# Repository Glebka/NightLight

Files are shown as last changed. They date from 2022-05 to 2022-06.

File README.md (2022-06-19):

# NightLight

This is device that will shade some light on your road to the kitchen at night :)

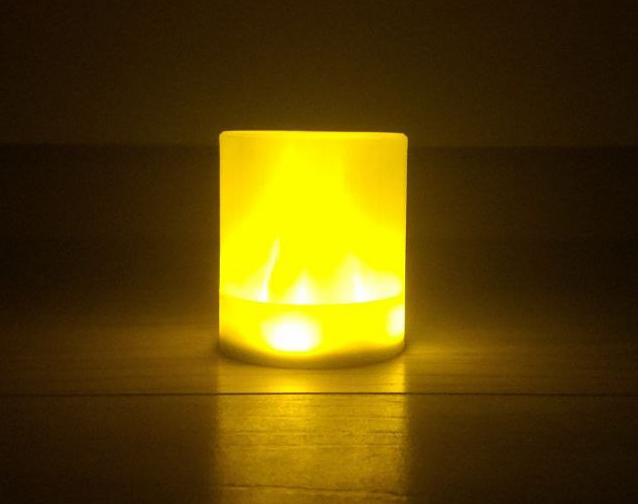
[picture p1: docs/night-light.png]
NightLight device


Well, this is simple electric LED light that powers from small Li-Pol cell (around 60 mAh capacity).

It supports three modes:
- **Off** - no light, charging enabled
- **Always on** - light always on
- **On for a period of time after motion detected** - yep, I've integrated a cheap microwave motion detector. When it triggers - the light turns on for approximately 3 minutes (that is enough time to grab something tasty in the kitchen and get back) and then turns off automatically.

## 3D View

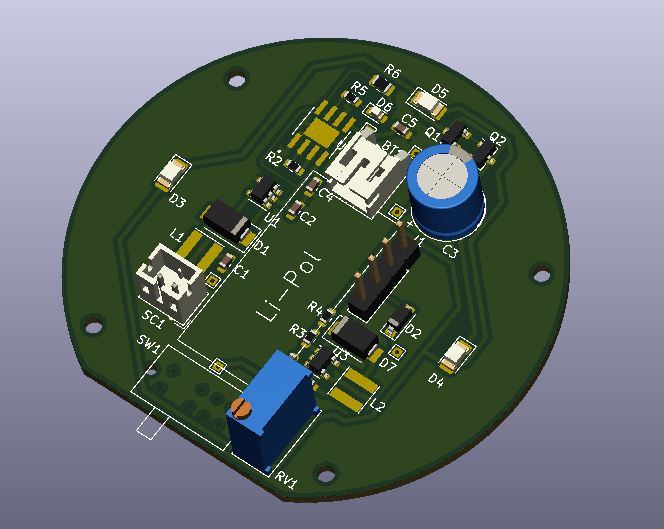
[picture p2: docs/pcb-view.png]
PCB in 3D


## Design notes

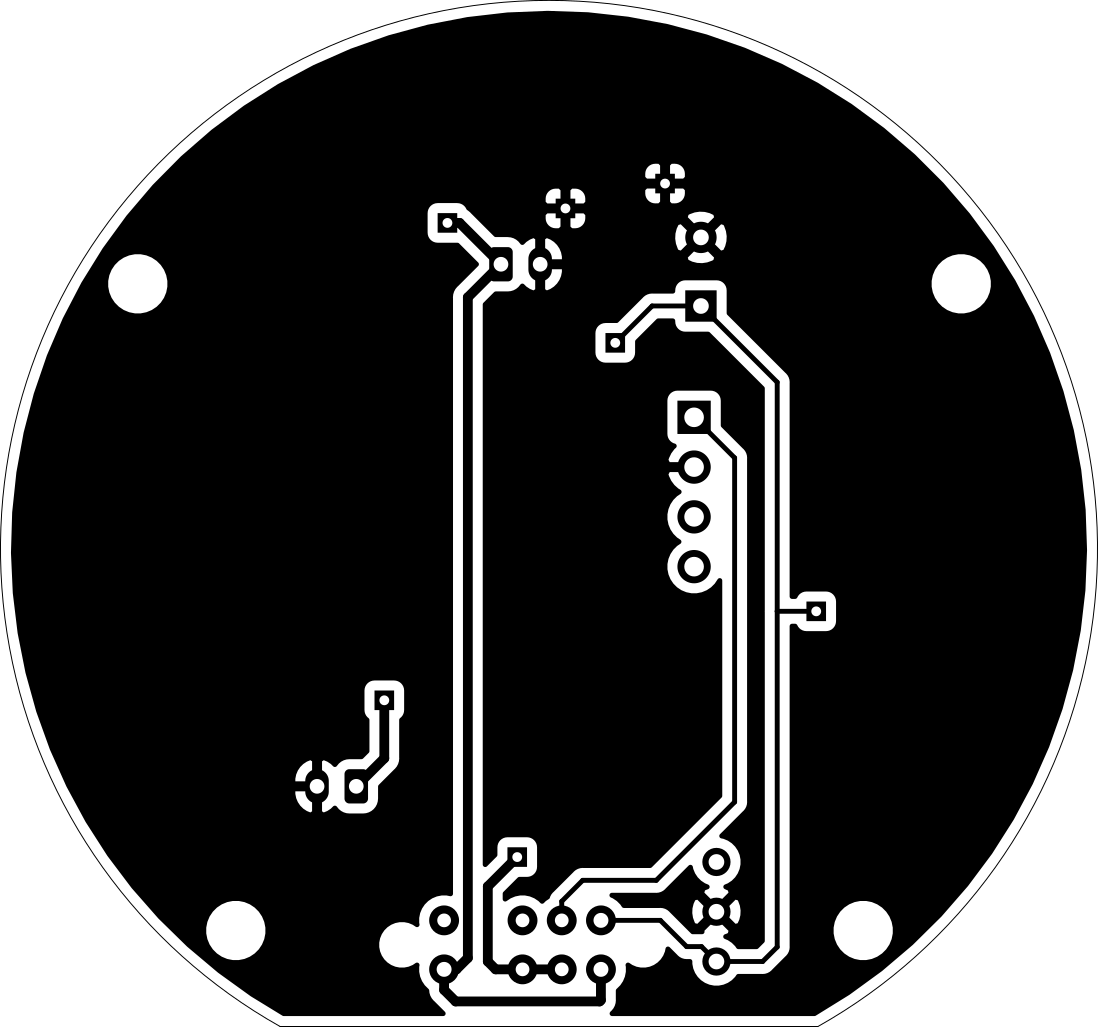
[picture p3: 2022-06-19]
cad/electronics/v2/svg/b-cu.png

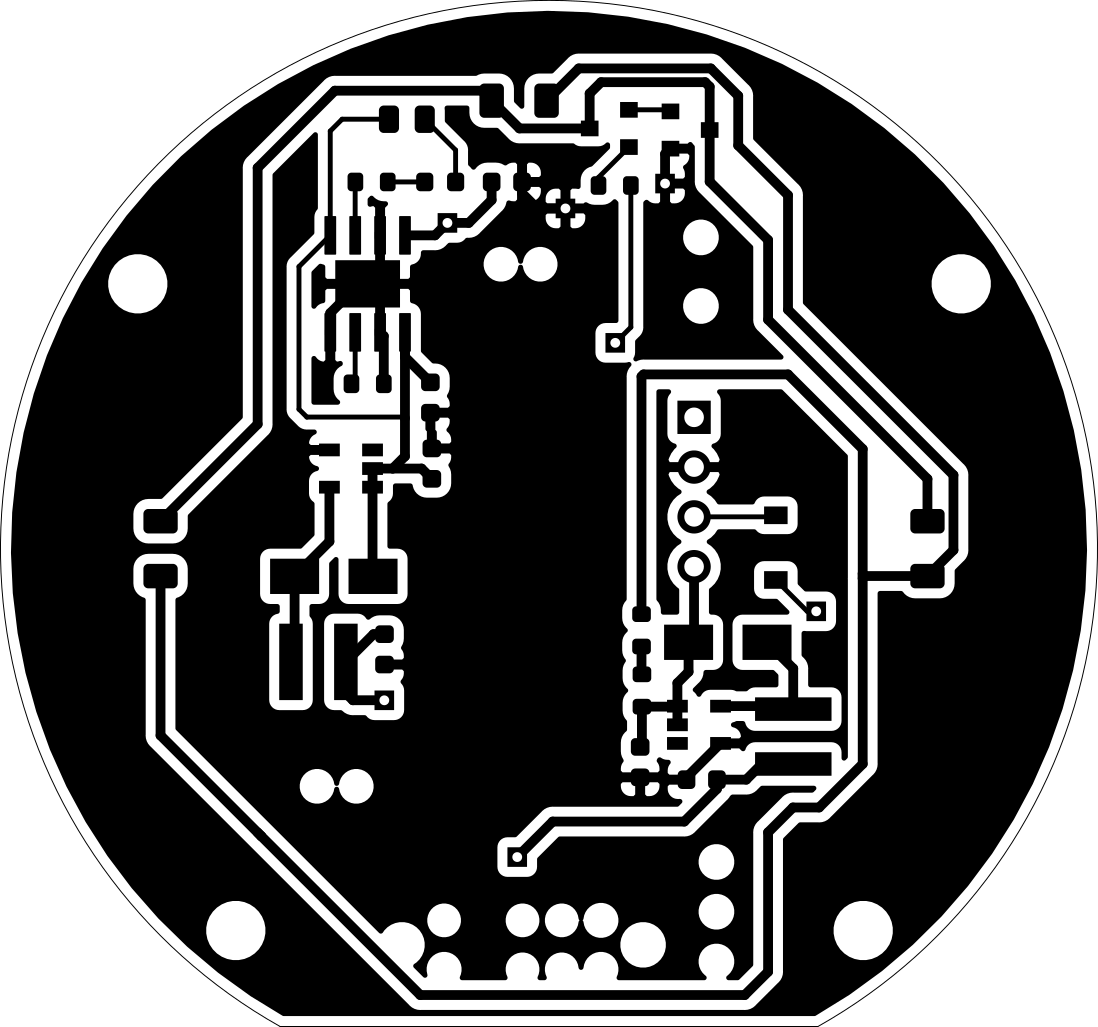
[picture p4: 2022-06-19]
cad/electronics/v2/svg/f-cu.png

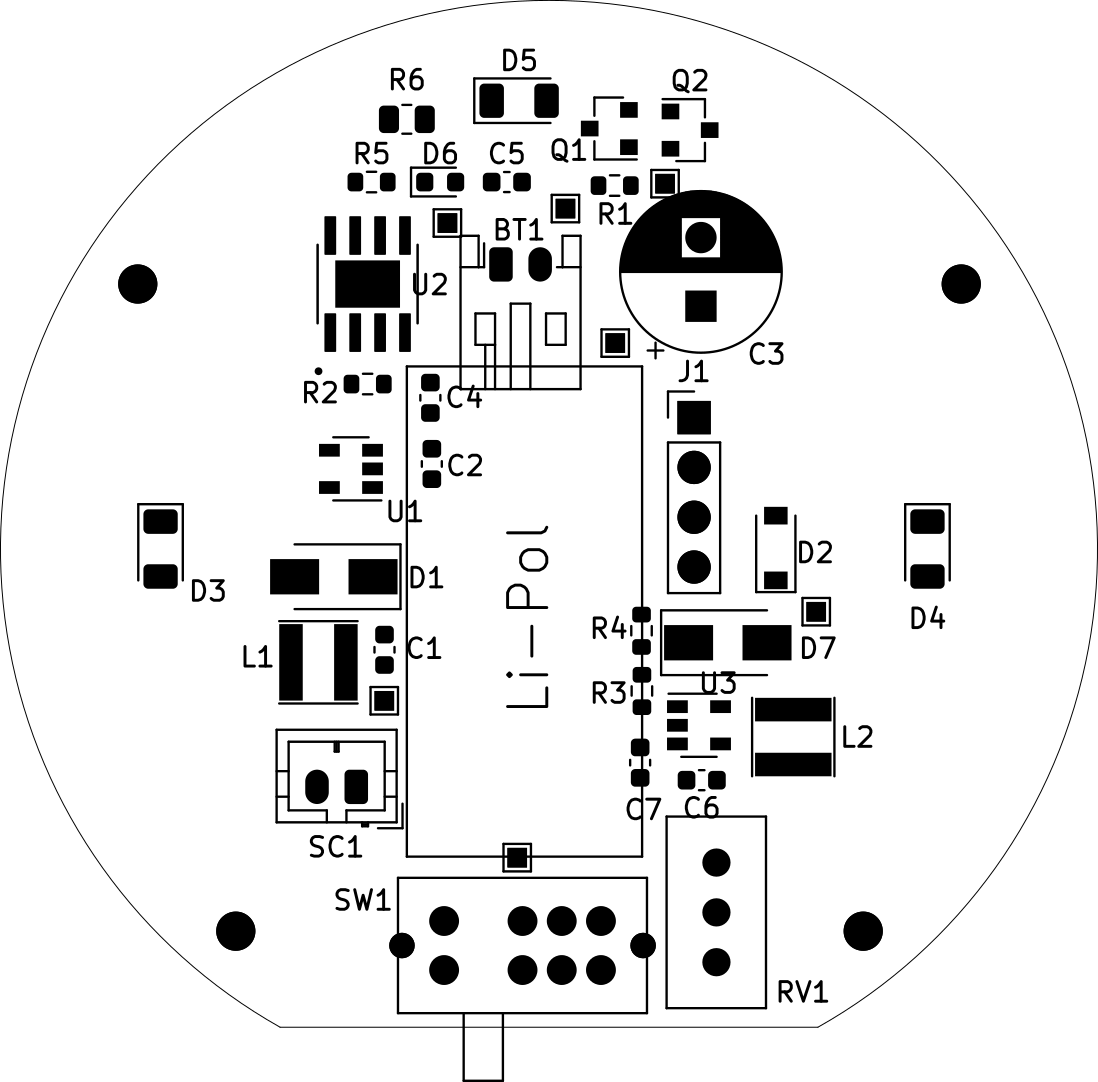
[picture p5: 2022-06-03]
cad/electronics/v2/svg/preview.png

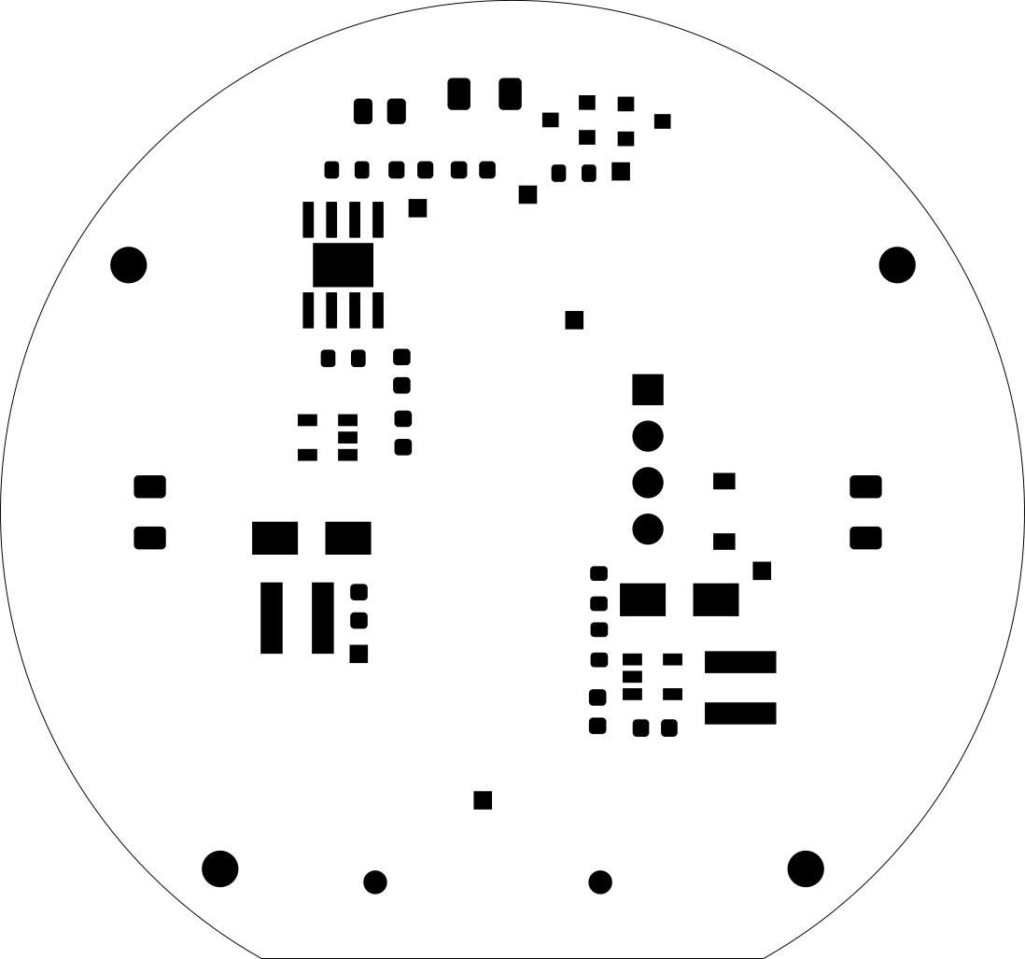
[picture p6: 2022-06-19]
cad/electronics/v2/svg/f-mask.png

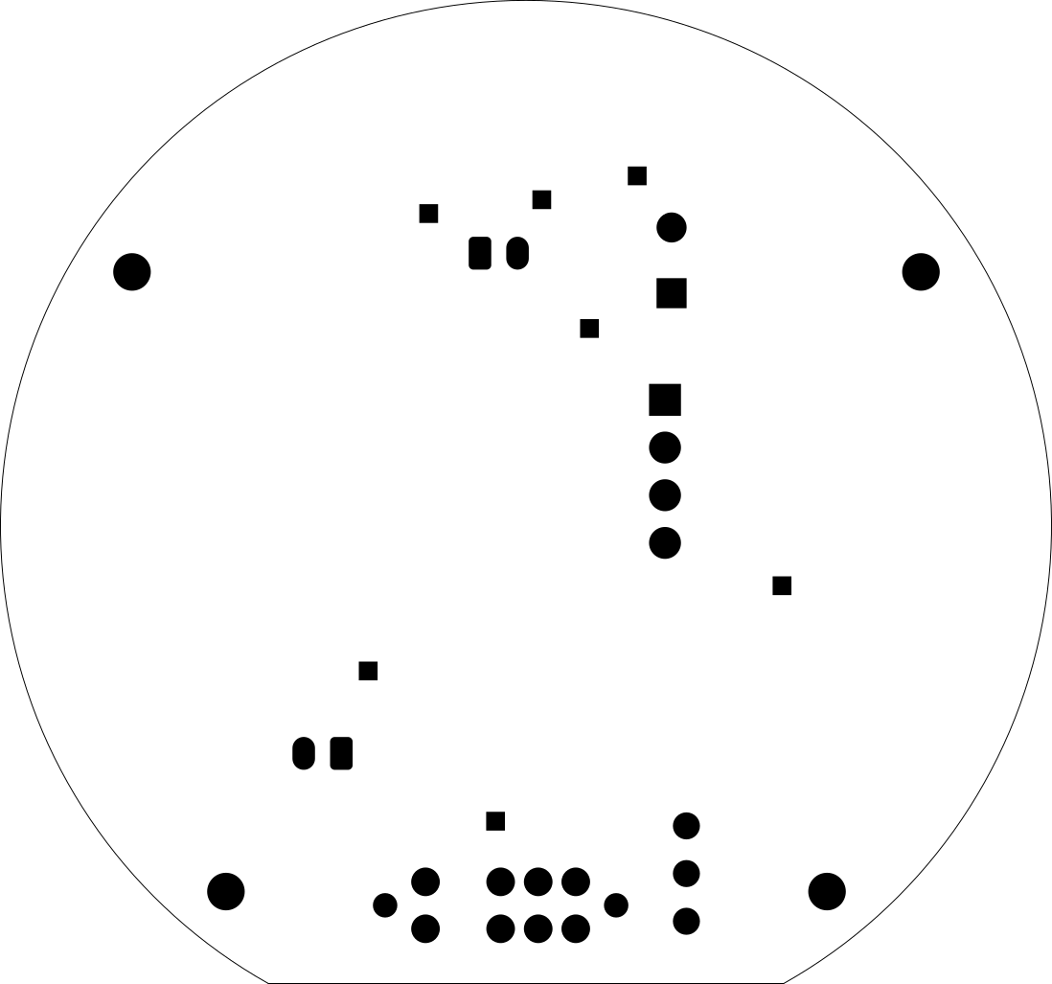
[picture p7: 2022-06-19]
cad/electronics/v2/svg/b-mask.png

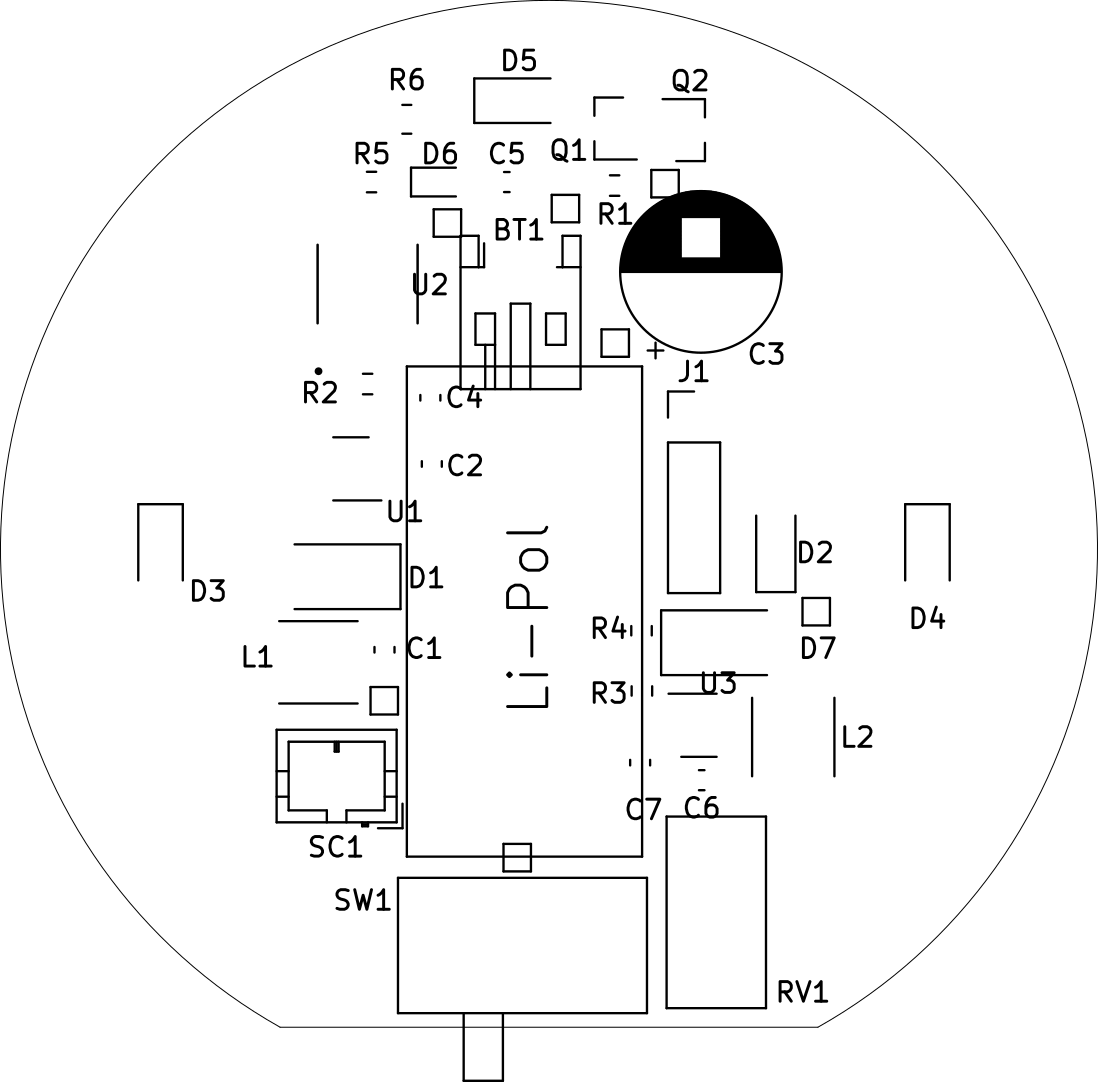
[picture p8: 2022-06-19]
cad/electronics/v2/svg/f-silk.png

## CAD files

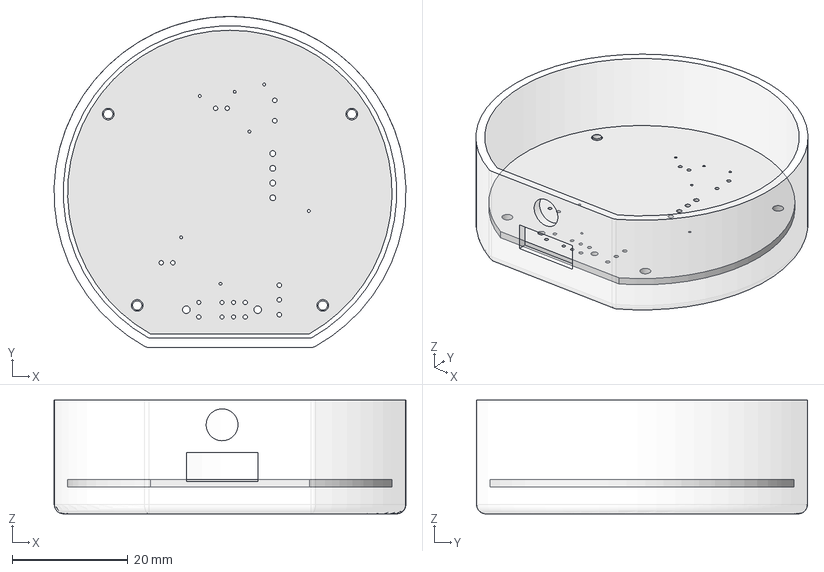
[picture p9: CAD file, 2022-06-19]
cad/chassis/nigh-light-assembly.FCStd
60.7 x 57.1 x 19.6 mm
ChassisBase
night-light_001

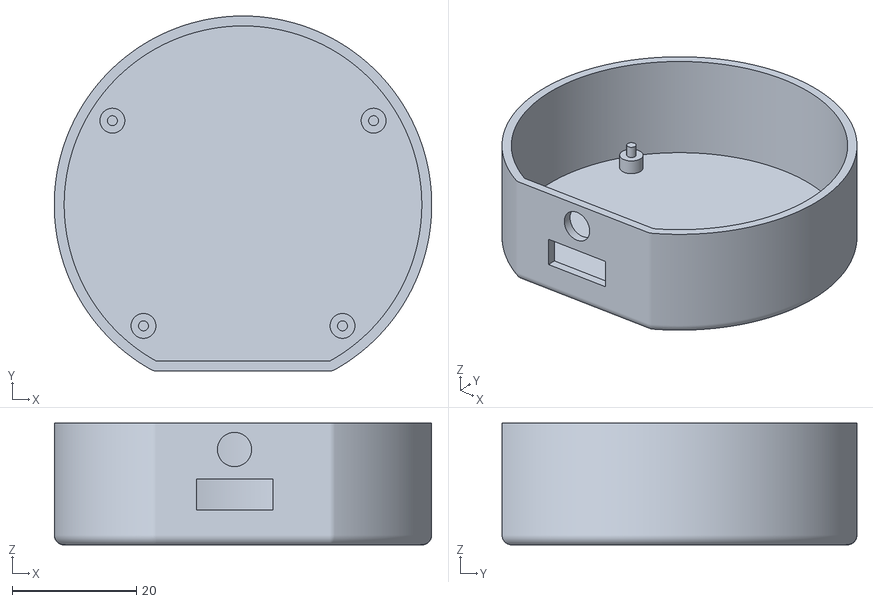
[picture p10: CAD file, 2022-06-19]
cad/chassis/stl/white-base.stl
60.7 x 57.1 x 19.6

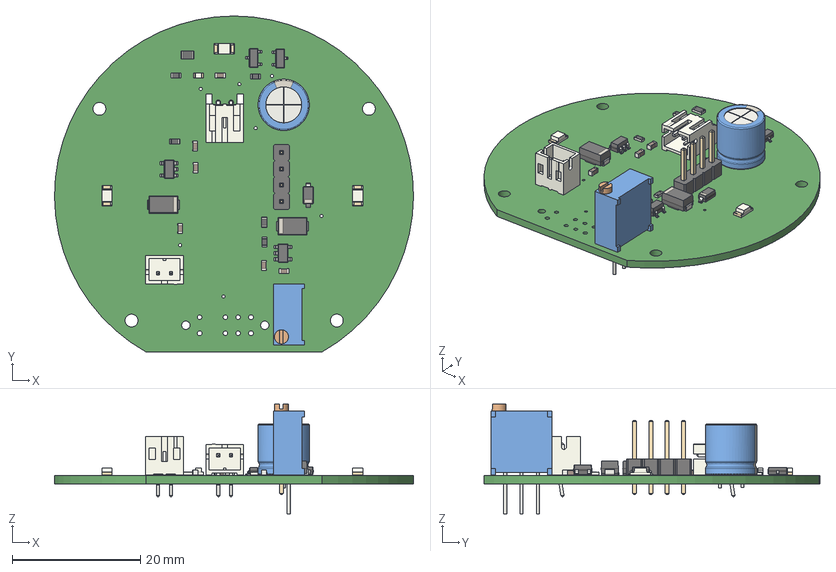
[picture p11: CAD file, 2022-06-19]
cad/electronics/v2/night-light.step
56.0 x 52.4 x 17.1 mm

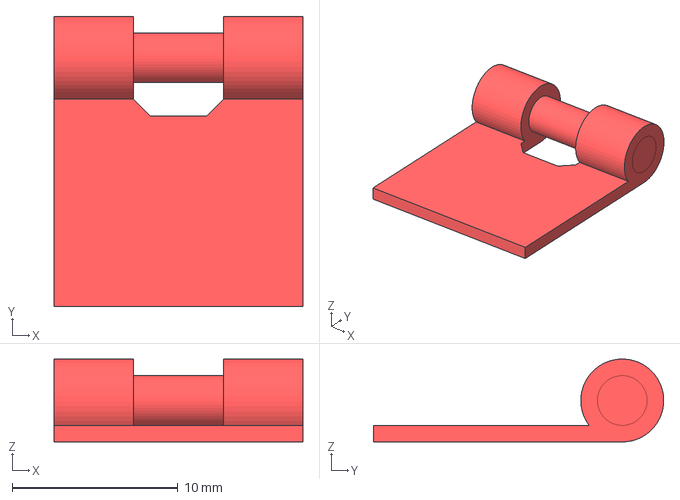
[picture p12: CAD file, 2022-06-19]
cad/chassis/night-light.FCStd
15.0 x 17.5 x 5.00 mm

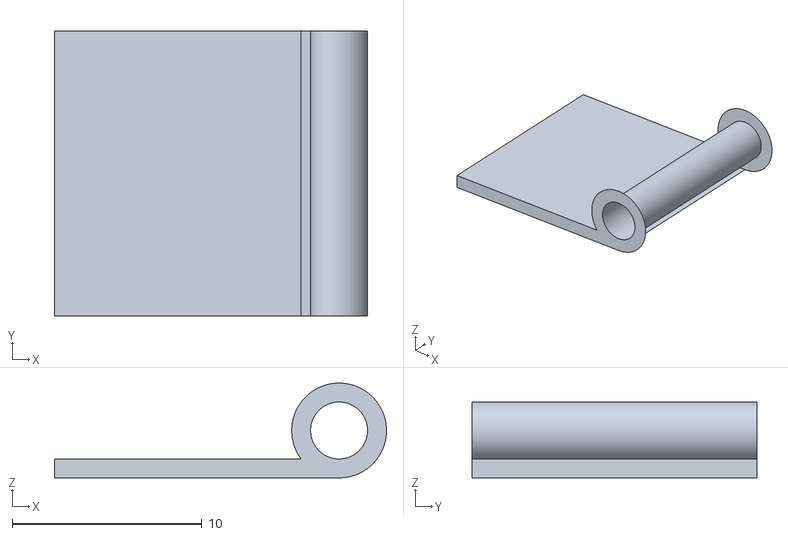
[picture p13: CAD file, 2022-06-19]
cad/chassis/stl/hinge-test.stl
17.5 x 15.0 x 5.00

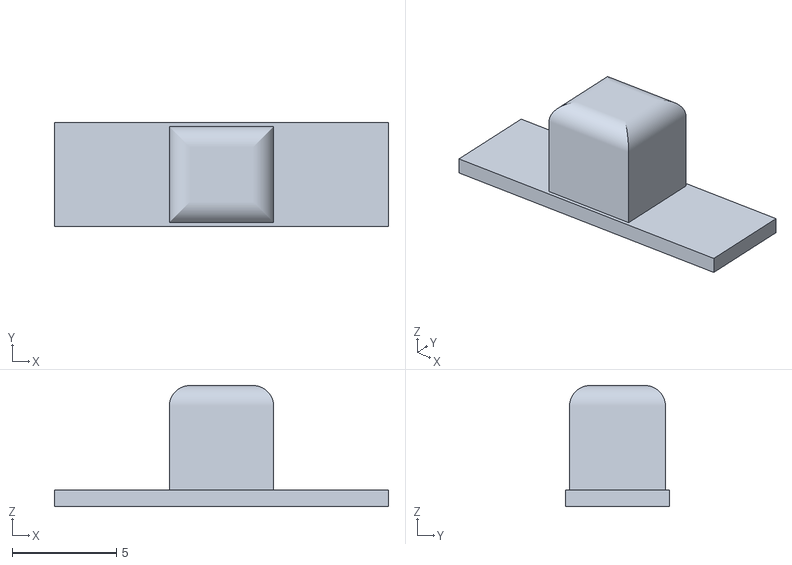
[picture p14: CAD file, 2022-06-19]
cad/chassis/stl/switch-body.stl
16.0 x 5.00 x 5.80

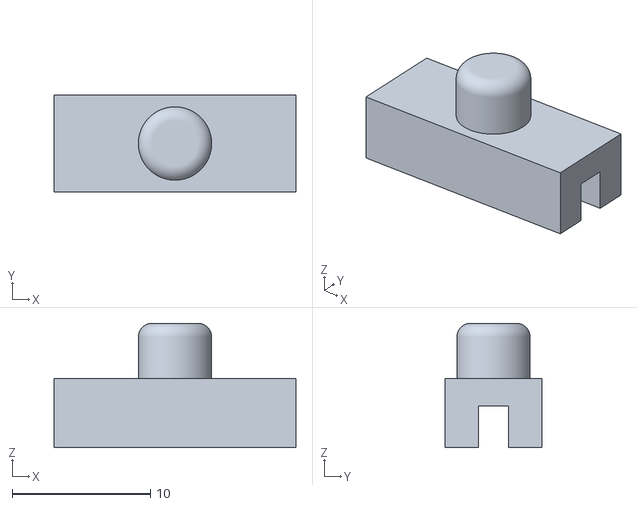
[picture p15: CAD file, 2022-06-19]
cad/chassis/stl/sensor-holder.stl
17.5 x 7.00 x 9.00

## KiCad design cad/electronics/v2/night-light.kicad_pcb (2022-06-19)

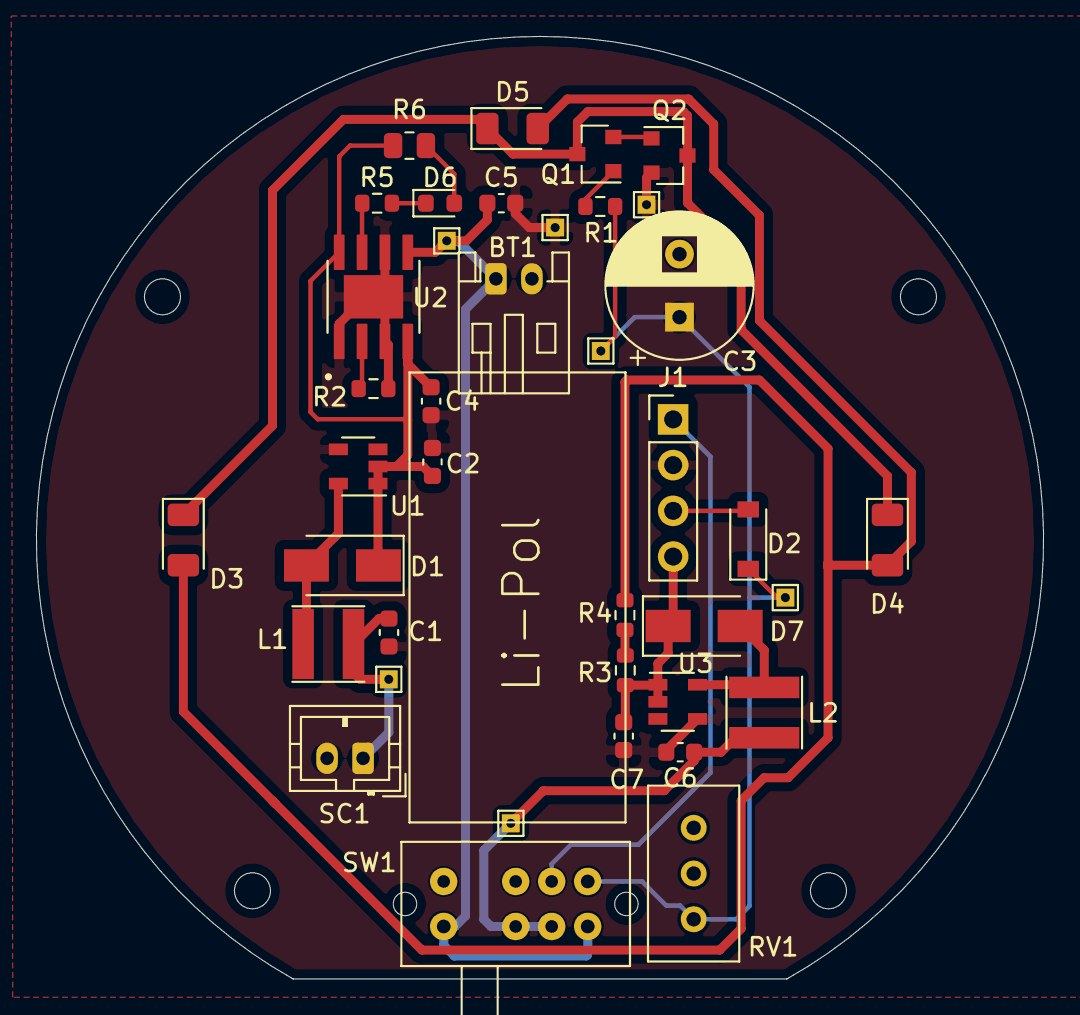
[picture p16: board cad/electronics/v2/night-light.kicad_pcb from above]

Board: 2 copper layers, 55.9 x 52.4 mm, 32 parts (0 on the bottom side), 20 nets.

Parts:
BT1: LiPol,60mAh; JST_PH_S2B-PH-K_1x02_P2.00mm_Horizontal
C1, C2, C6, C7: 4.7uF; C_0603_1608Metric
C3: 470uF; CP_Radial_D8.0mm_P3.50mm
C4, C5: 10uF; C_0603_1608Metric
D1, D7: SS14; D_SMA
D2: 1N5819; D_SOD-123
D3, D4, D5: LED; LED_1206_3216Metric
D6: LED-Y; LED_0603_1608Metric
J1: RWCL-0516; PinHeader_1x04_P2.54mm_Vertical
L1, L2: 47uH; L_Taiyo-Yuden_NR-40xx
Q1, Q2: MMBT3904; SOT-23
R1: 470k; R_0603_1608Metric
R2: 18k; R_0603_1608Metric
R3: 150R; R_0603_1608Metric
R4: 82R; R_0603_1608Metric
R5: 3k; R_0603_1608Metric
R6: 0R; R_0805_2012Metric
RV1: BAOTER 3296; Potentiometer_Bourns_3296W_Vertical
SC1: 5V, 0.125W; JST_PH_B2B-PH-K_1x02_P2.00mm_Vertical
SW1: L-KLS7-SK35-23D07-VG3
U1, U3: NCP1402SN50T1G; SOT-23-5
U2: TP4056; SOP127P600X175-9N

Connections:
3V3: J1.1, SW1.7
5V: C7.1, D7.1, J1.4, R3.1, U3.1, U3.2
A_ON: C3.1, D2.1, R1.2, RV1.1, SW1.8
BAT+: C6.1, L2.1, SW1.2, SW1.3
CH_IN: C2.1, C4.2, D1.1, R6.2, U1.1, U1.2, U2.4, U2.8
GND: BT1.2, C1.2, C2.2, C3.2, C4.1, C5.2, C6.2, C7.2, J1.2, Q2.2, R2.1, RV1.2, SC1.2, U1.4, U2.1, U2.3, U2.6, U2.9, U3.4
MOTION: D2.2, J1.3
unnamed: C1.1, L1.1, SC1.1
unnamed: D1.2, L1.2, U1.5
unnamed: D3.1, D4.1, D5.1, Q1.3, Q2.3
unnamed: D3.2, D4.2, D5.2, R4.2
unnamed: D6.1, R5.2
unnamed: D6.2, R6.1
unnamed: D7.2, L2.2, U3.5
unnamed: Q1.1, R1.1
unnamed: Q1.2, Q2.1
unnamed: R2.2, U2.2
unnamed: R3.2, R4.1
unnamed: R5.1, U2.7
VBAT: BT1.1, C5.1, SW1.1, SW1.4, U2.5

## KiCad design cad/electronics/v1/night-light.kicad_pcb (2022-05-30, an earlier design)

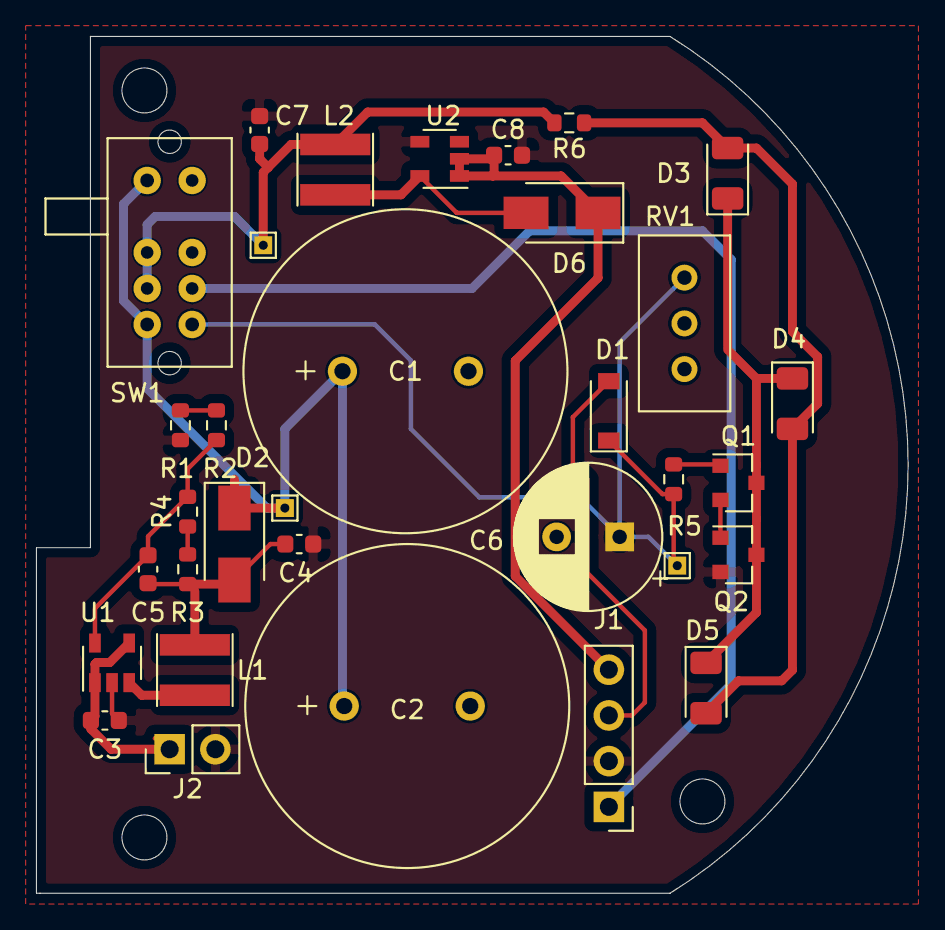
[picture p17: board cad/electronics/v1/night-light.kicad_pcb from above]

Board: 2 copper layers, 48.4 x 47.6 mm, 30 parts (0 on the bottom side), 18 nets.

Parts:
C1, C2: 50F; SMAXON-DRL-2.7V-50F
C3, C4, C7, C8: 4.7uF; C_0603_1608Metric
C5: 1nF(102); C_0603_1608Metric
C6: 470uF; CP_Radial_D8.0mm_P3.50mm
D1: 1N5819; D_SOD-123
D2, D6: SS14; D_SMA
D3, D4, D5: LED; LED_1206_3216Metric
J1: RWCL-0516; PinHeader_1x04_P2.54mm_Vertical
J2: Solar Cell; PinHeader_1x02_P2.54mm_Vertical
L1: 4.7uH; L_Taiyo-Yuden_NR-40xx
L2: 47uH; L_Taiyo-Yuden_NR-40xx
Q1, Q2: MMBT3904; SOT-23
R1: 51k; R_0603_1608Metric
R2, R4: 200k; R_0603_1608Metric
R3: 680k; R_0603_1608Metric
R5: 470k; R_0603_1608Metric
R6: 62; R_0603_1608Metric
RV1: BAOTER 3296; Potentiometer_Bourns_3296W_Vertical
SW1: L-KLS7-SK35-23D07-VG3
U1: NCP1529A; SOT-23-5
U2: NCP1402SN50T1G; SOT-23-5

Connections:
+3V3: J1.1, SW1.7
+5V: C8.1, D6.1, J1.4, U2.1, U2.2
A_ON: C6.1, D1.1, R5.2, RV1.1, SW1.8
BAT+: C7.1, L2.1, R6.2, SW1.2, SW1.3
MOTION: D1.2, J1.3
unnamed: C4.2, C5.1, D2.2, L1.2, R3.1
unnamed: C5.2, R2.1, R4.2, U1.5
unnamed: D3.1, D4.1, D5.1, Q1.3, Q2.3
unnamed: D3.2, D4.2, D5.2, R6.1
unnamed: D6.2, L2.2, U2.5
unnamed: L1.1, U1.3
unnamed: Q1.1, R5.1
unnamed: Q1.2, Q2.1
unnamed: R1.1, R2.2
unnamed: R3.2, R4.1
SOL+: C3.1, J2.1, U1.1, U1.4
SOL-: C1.2, C2.2, C3.2, C4.1, C6.2, C7.2, C8.2, J1.2, J2.2, Q2.2, R1.2, RV1.2, U1.2, U2.4
Vch: C1.1, C2.1, D2.1, SW1.1, SW1.4

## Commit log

2022-06-03 Imlement device v2 with Li-Pol battery
    [night-light.kicad_pcb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]
2022-06-19 Update files according to latest design
    [hinge-test.stl, nigh-light-assembly.FCStd, night-light.FCStd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]
